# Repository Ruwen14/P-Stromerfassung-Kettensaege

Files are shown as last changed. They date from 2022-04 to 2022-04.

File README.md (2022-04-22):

# P-Stromerfassung-Kettensaege
Projektarbeit: Schaltungstechnik Master Mechatronik
- Aufgabenstellung:
  Messung des Dreiphasenstrom eines BLDC-Motors in einer Kettensäge

- Genutzte Technologien:
  -   LTSpice (Simulation)
  -   Eagle (Platinendesign & Layout)
  -   Reflow Ofen & Löteisen (Bestückung)

# Schematic
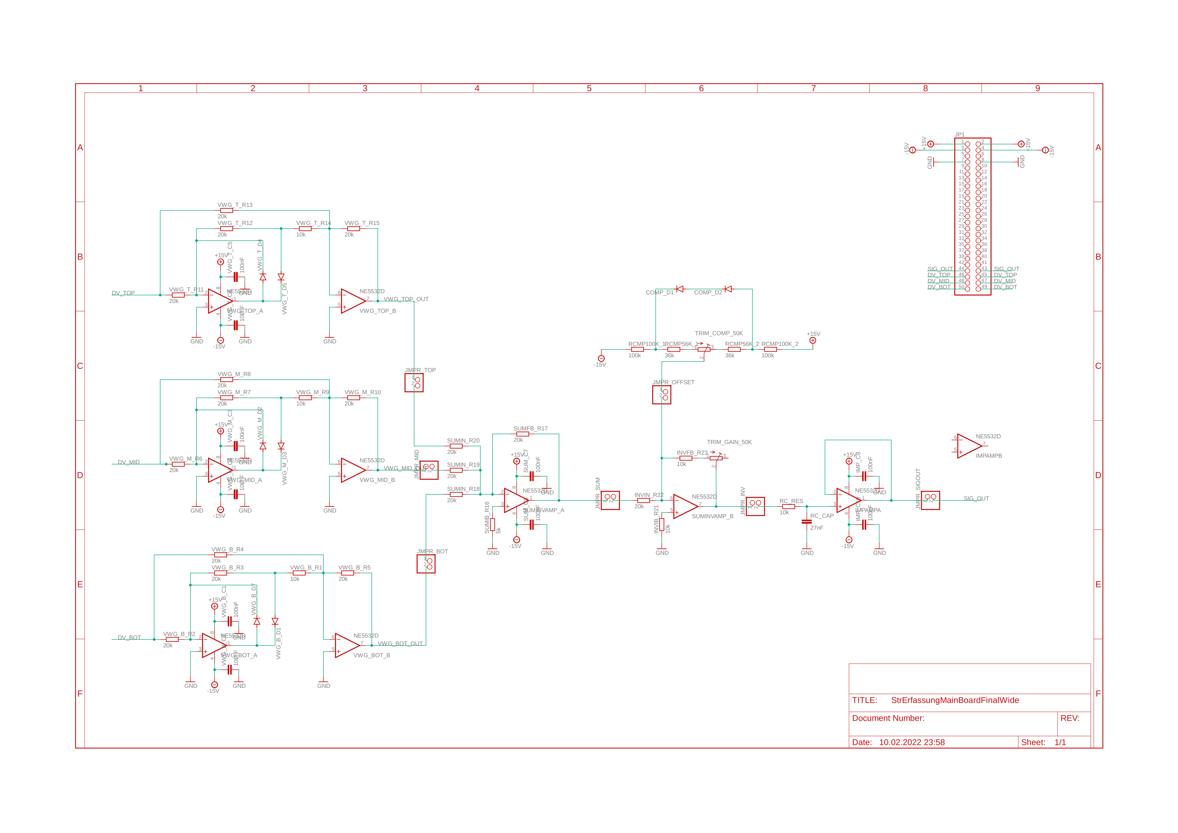
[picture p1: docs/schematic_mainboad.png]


# PCB
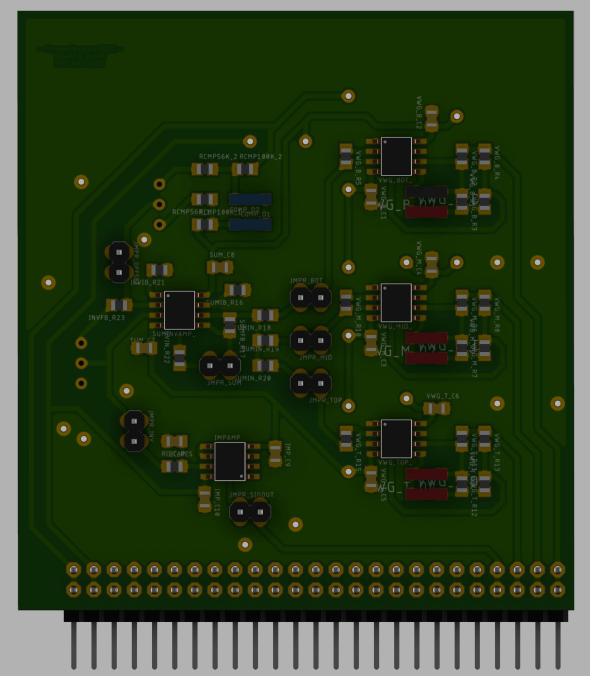
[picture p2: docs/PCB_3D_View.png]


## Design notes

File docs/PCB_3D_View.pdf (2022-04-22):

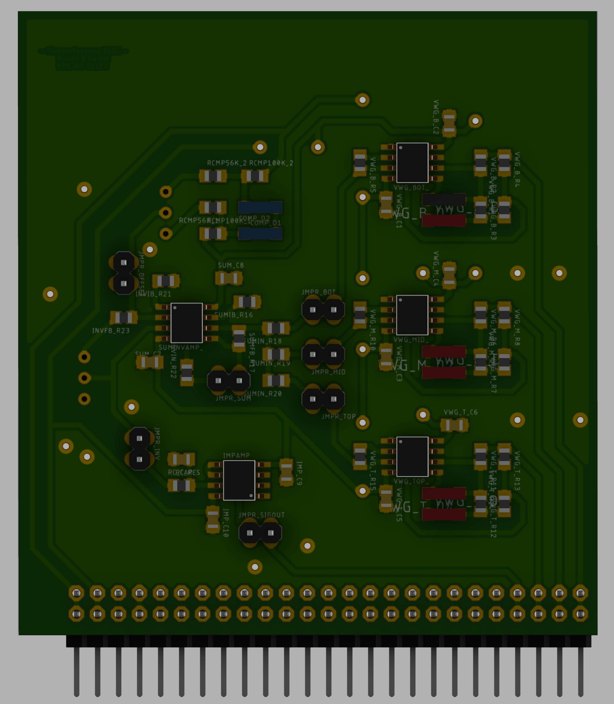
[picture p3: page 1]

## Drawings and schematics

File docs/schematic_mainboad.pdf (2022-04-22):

A

A

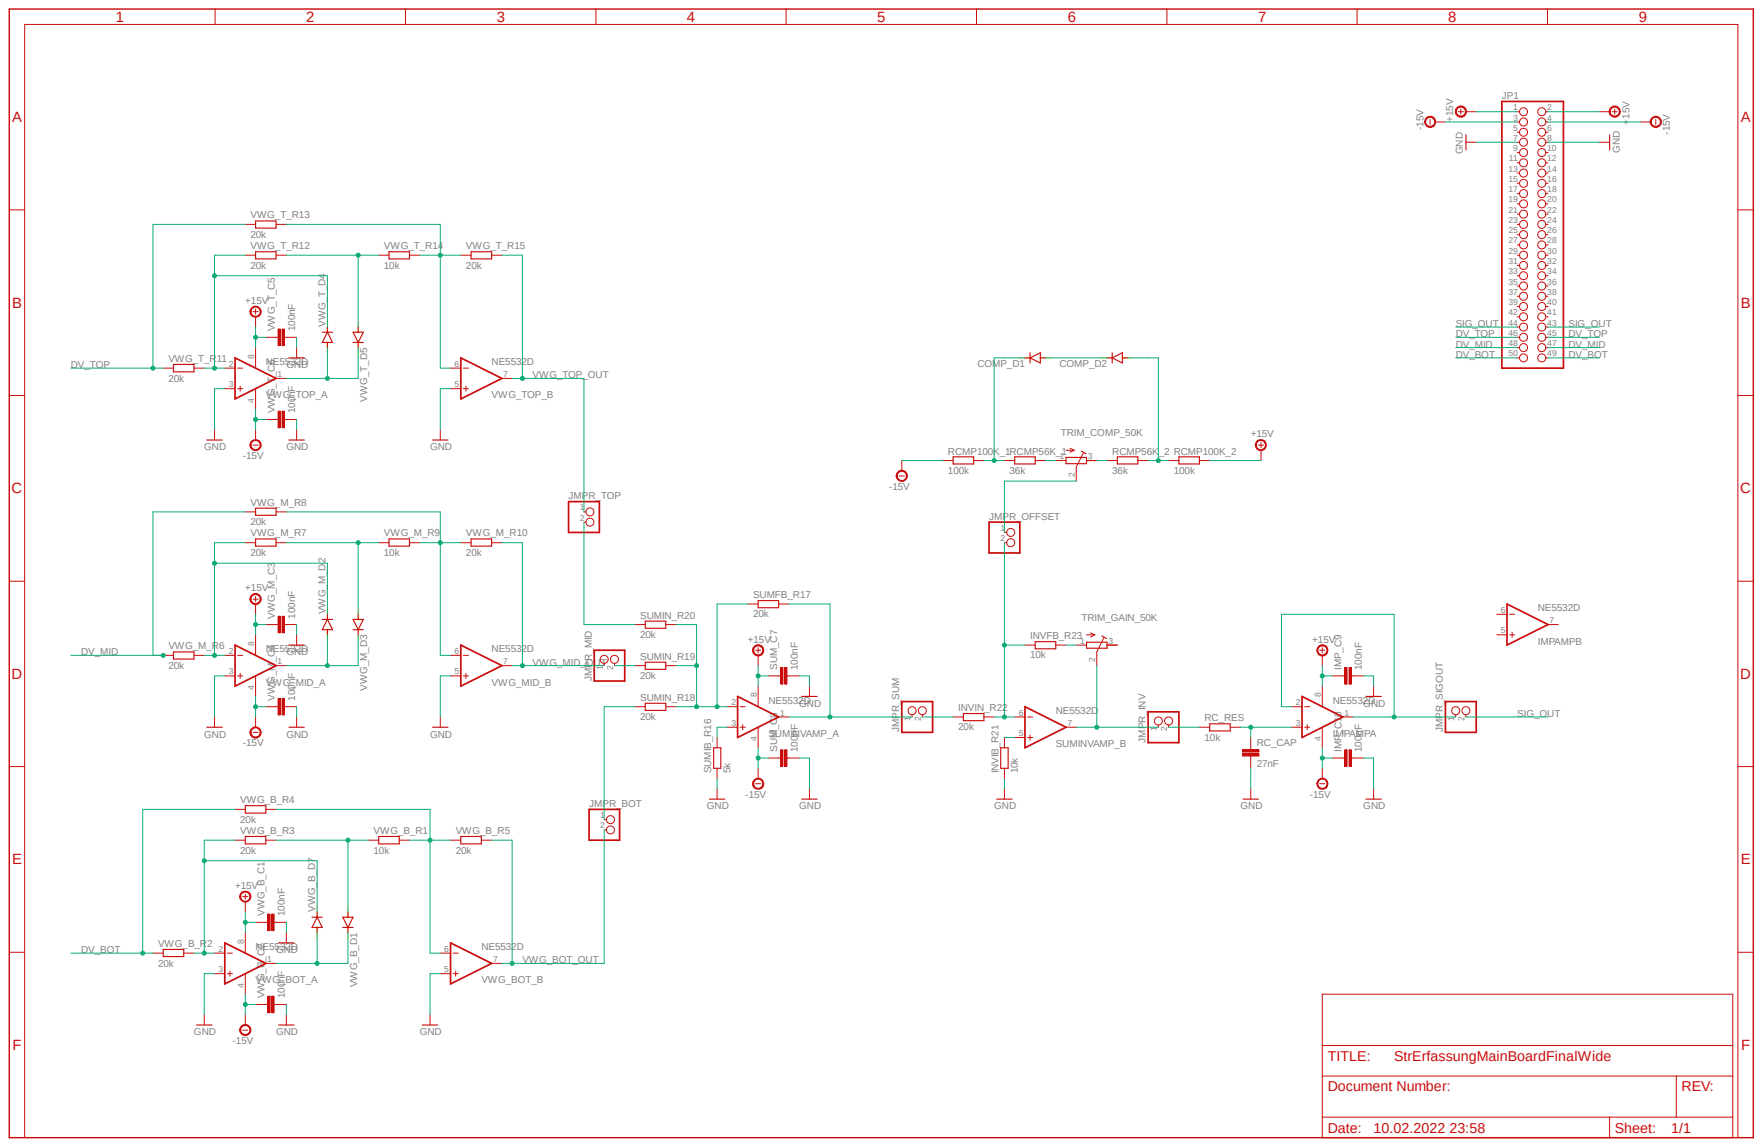
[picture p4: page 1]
SpiceOrder 2; SpiceOrder 1 SpiceOrder 1; GND; 100nF GND; 100nF GND ⁵k; VWG_BOT_A; VWG_BOT_B; VWG_B_R2; VWG_B_R3; VWG_B_R4; VWG_B_R1; VWG_B_R5 8 4; VWG_B_C¹ VWG_B_C²; VWG_MID_A; VWG_MID_B; VWG_M_R6; VWG_M_R7; VWG_M_R8; VWG_M_R9; VWG_M_R10 8 4; VWG_M_C³ VWG_M_C⁴; VWG_TOP_A; VWG_TOP_B; VWG_T_R11; VWG_T_R12; VWG_T_R13; VWG_T_R14; VWG_T_R15 8 4; VWG_T_C⁵ VWG_T_C⁶; SUMINVAMP_A; SUMINVAMP_B ⁸ ⁴; SUM_C⁷ SUM_C⁸ SUMIB_R¹⁶; SUMFB_R17; SUMIN_R18; SUMIN_R19; SUMIN_R20; INVIB_R²¹; INVIN_R22; INVFB_R23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

SpiceOrder 1 SpiceOrder 2 SpiceOrder 1 SpiceOrder 2 SpiceOrder 1 SpiceOrder 2

Document Number: | REV:

Date: 10.02.2022 23:58 | Sheet: 1/1

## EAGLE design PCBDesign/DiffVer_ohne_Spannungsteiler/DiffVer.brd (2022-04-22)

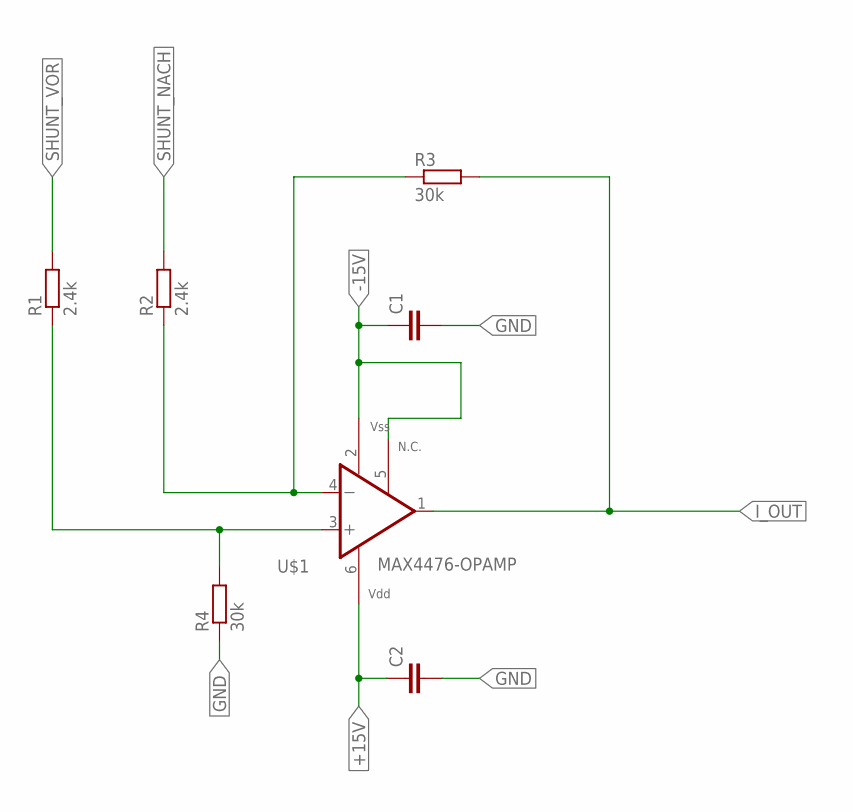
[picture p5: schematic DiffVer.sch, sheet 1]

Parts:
C1, C2: C-EUC0805; C0805
R1, R2: 2.4k; R0805
R3, R4: 30k; R0805
U$1: MAX4476-OPAMP; SOT23-6

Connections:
+15V: C2.1, U$1.6 (VDD); also elsewhere on the board
-15V: C1.1, U$1.2 (VSS), U$1.5 (NC); also elsewhere on the board
GND: C1.2, C2.2, R4.1; also elsewhere on the board
I_OUT: R3.2, U$1.1 (OUT); also elsewhere on the board
MINUS_OP: R2.1, R3.1, U$1.4 (-IN)
PLUS_OP: R1.1, R4.2, U$1.3 (+IN)
SHUNT_NACH: R2.2; also elsewhere on the board
SHUNT_VOR: R1.2; also elsewhere on the board

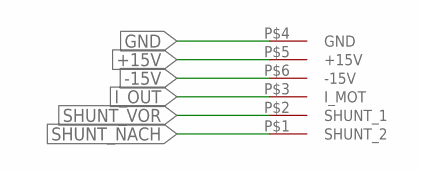
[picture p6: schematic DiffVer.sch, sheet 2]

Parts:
U$2: ADAPTERPLATINE_OPSHUNT

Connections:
+15V: U$2.P$5 (+15V); also elsewhere on the board
-15V: U$2.P$6 (-15V); also elsewhere on the board
GND: U$2.P$4 (GND); also elsewhere on the board
I_OUT: U$2.P$3 (I_MOT); also elsewhere on the board
SHUNT_NACH: U$2.P$1 (SHUNT_2); also elsewhere on the board
SHUNT_VOR: U$2.P$2 (SHUNT_1); also elsewhere on the board

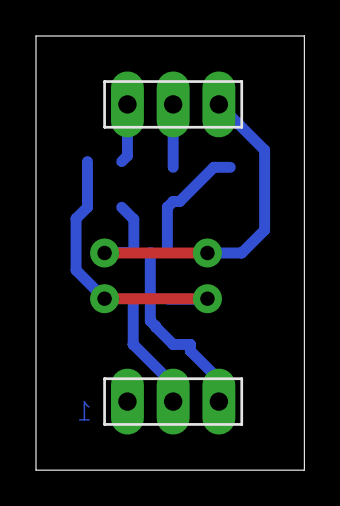
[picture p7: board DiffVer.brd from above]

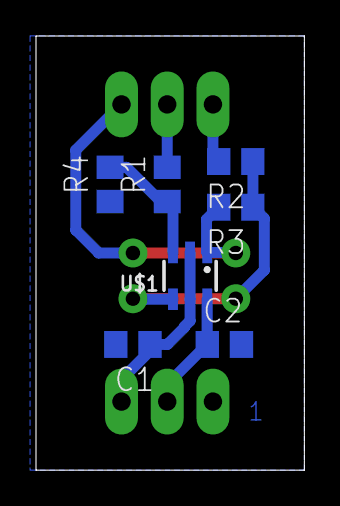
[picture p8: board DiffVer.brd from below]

Board: 2 copper layers, 14.9 x 24.1 mm, 8 parts (7 on the bottom side), 8 nets.

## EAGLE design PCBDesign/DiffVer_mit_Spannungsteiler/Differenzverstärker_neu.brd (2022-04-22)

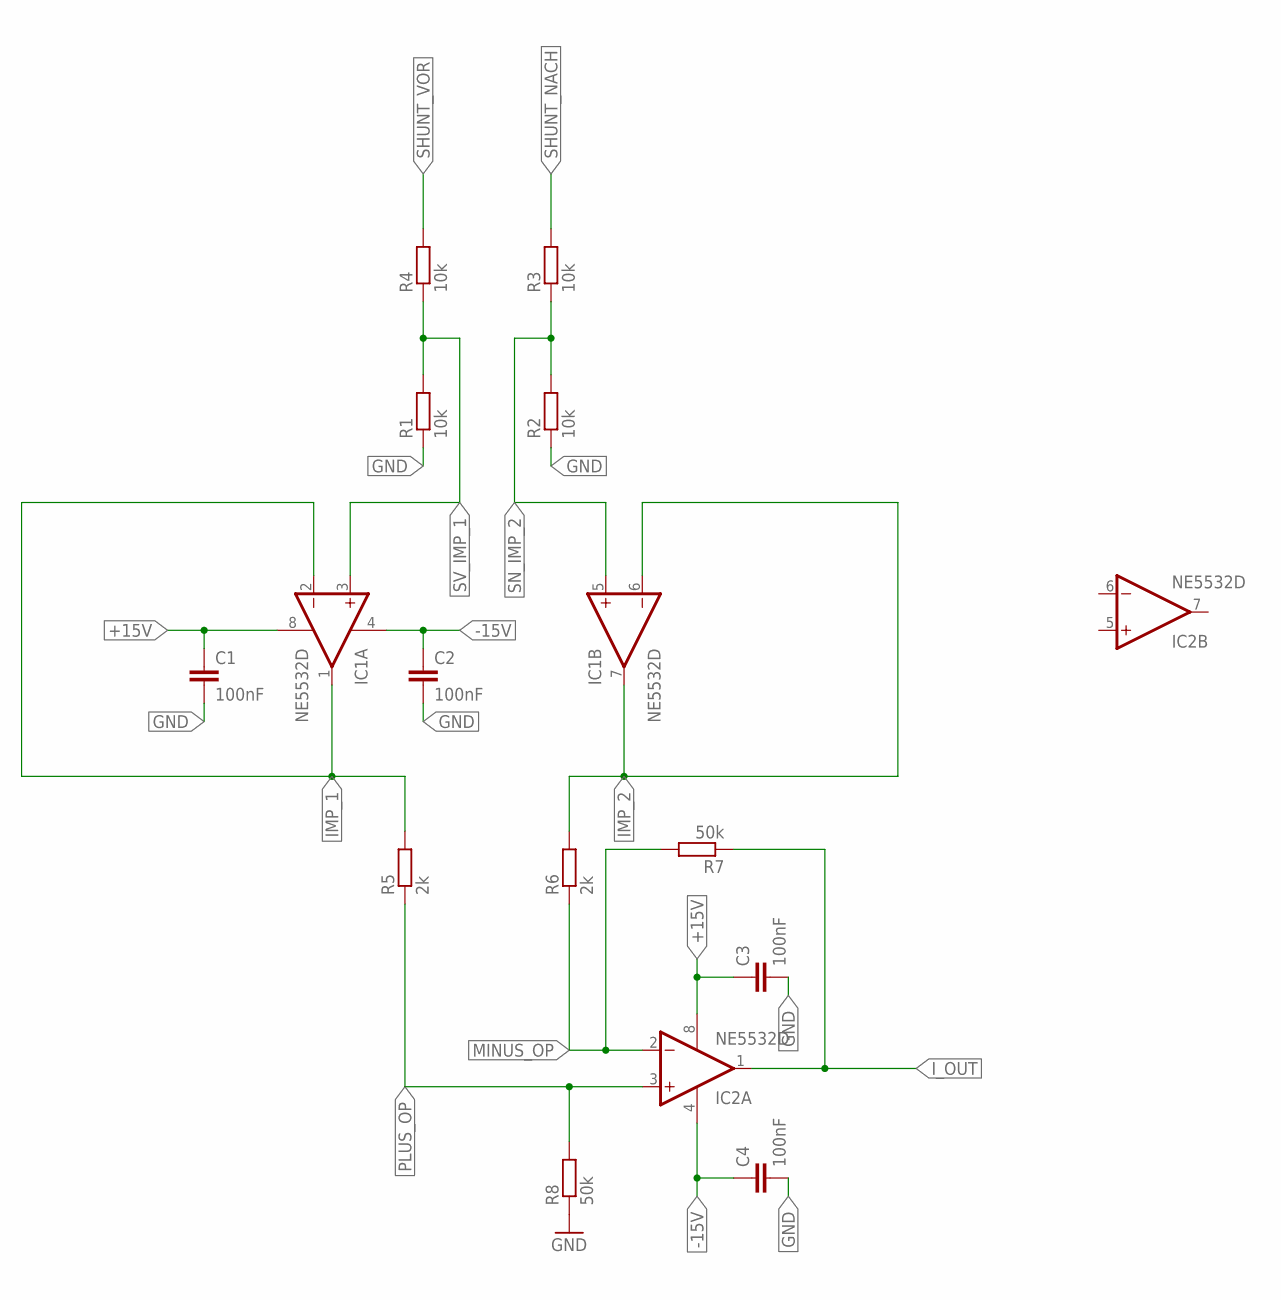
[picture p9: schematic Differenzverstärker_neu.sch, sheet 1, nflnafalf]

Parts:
C1, C2, C3, C4: 100nF; C0805
IC1, IC2: NE5532D; SO08
R1, R2, R3, R4: 10k; R0805
R5, R6: 2k; R0805
R7, R8: 50k; R0805

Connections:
+15V: C1.1, C3.1, IC1.8 (V+), IC2.8 (V+); also elsewhere on the board
-15V: C2.1, C4.1, IC1.4 (V-), IC2.4 (V-); also elsewhere on the board
GND: C1.2, C2.2, C3.2, C4.2, R1.1, R2.1, R8.1; also elsewhere on the board
IMP_1: IC1.1 (OUT), IC1.2 (-IN), R5.2
IMP_2: IC1.6 (-IN), IC1.7 (OUT), R6.2
I_OUT: IC2.1 (OUT), R7.1; also elsewhere on the board
MINUS_OP: IC2.2 (-IN), R6.1, R7.2
PLUS_OP: IC2.3 (+IN), R5.1, R8.2
SHUNT_NACH: R3.2; also elsewhere on the board
SHUNT_VOR: R4.2; also elsewhere on the board
SN_IMP_2: IC1.5 (+IN), R2.2, R3.1
SV_IMP_1: IC1.3 (+IN), R1.2, R4.1


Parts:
U$2: ADAPTERPLATINE_OPSHUNT

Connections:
+15V: U$2.P$5 (+15V); also elsewhere on the board
-15V: U$2.P$6 (-15V); also elsewhere on the board
GND: U$2.P$4 (GND); also elsewhere on the board
I_OUT: U$2.P$3 (I_MOT); also elsewhere on the board
SHUNT_NACH: U$2.P$1 (SHUNT_2); also elsewhere on the board
SHUNT_VOR: U$2.P$2 (SHUNT_1); also elsewhere on the board

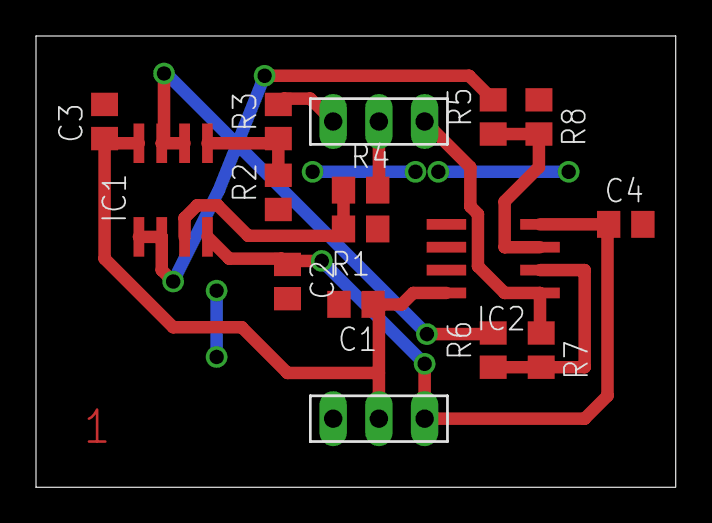
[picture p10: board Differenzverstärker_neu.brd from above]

Board: 2 copper layers, 35.5 x 25.1 mm, 15 parts (0 on the bottom side), 12 nets.

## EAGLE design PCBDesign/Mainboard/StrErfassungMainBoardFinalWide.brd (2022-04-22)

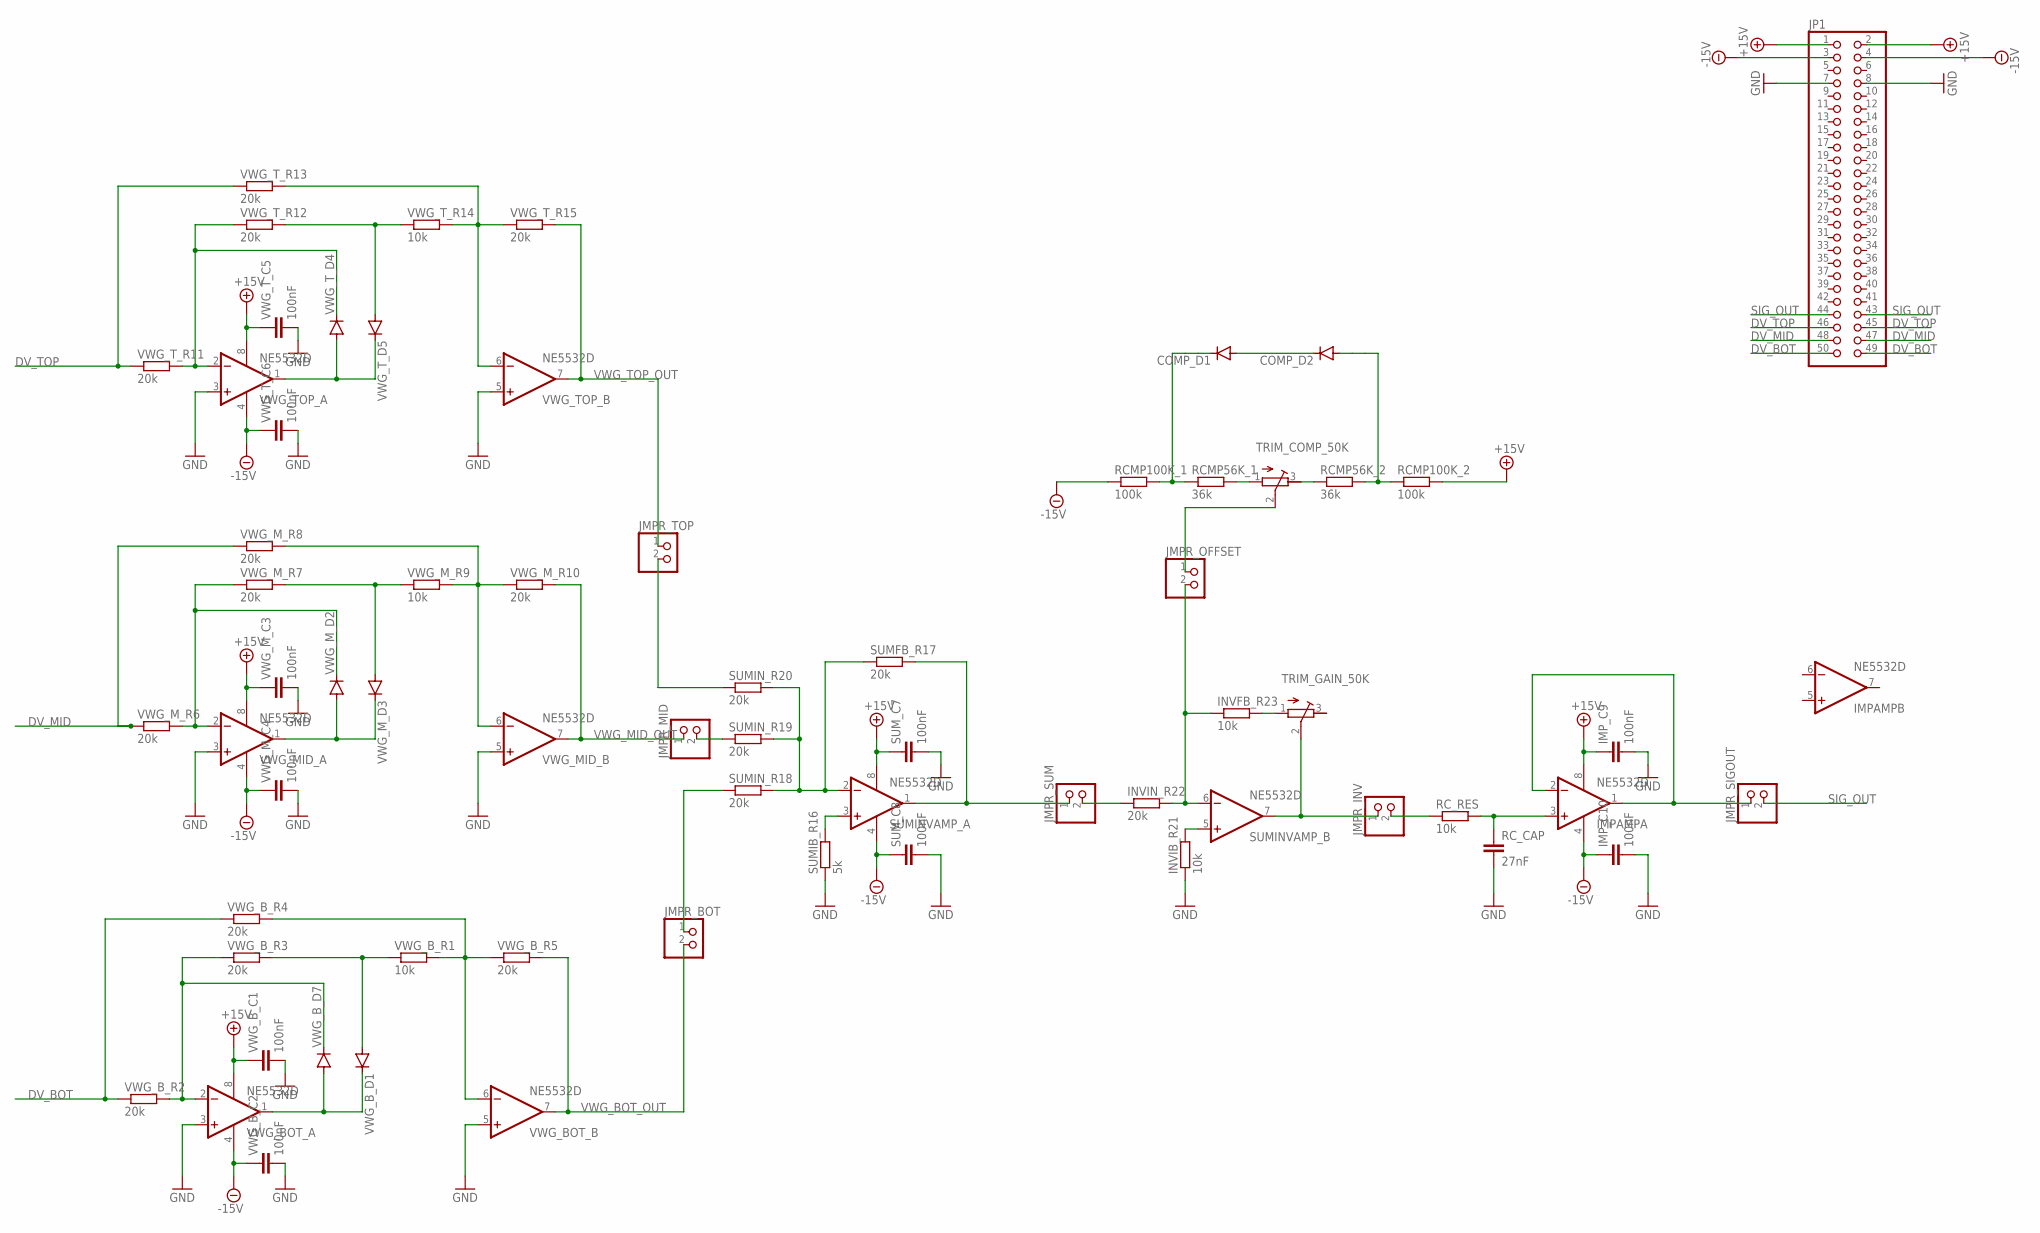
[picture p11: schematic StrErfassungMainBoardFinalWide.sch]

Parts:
COMP_D1, COMP_D2: DIODE-SOD123; SOD123
IMPAMP: NE5532D; SO08
IMP_C9, IMP_C10: 100nF; C0805
INVFB_R23: 10k; R0805
INVIB_R21: 10k; R0805
INVIN_R22: 20k; R0805
JMPR_BOT: PINHD-1X2; 1X02
JMPR_INV: PINHD-1X2; 1X02
JMPR_MID: PINHD-1X2; 1X02
JMPR_OFFSET: PINHD-1X2; 1X02
JMPR_SIGOUT: PINHD-1X2; 1X02
JMPR_SUM: PINHD-1X2; 1X02
JMPR_TOP: PINHD-1X2; 1X02
JP1: PINHD-2X25/90; 2X25/90
RCMP56K_1, RCMP56K_2: 36k; R0805
RCMP100K_1, RCMP100K_2: 100k; R0805
RC_CAP: 27nF; C0805
RC_RES: 10k; R0805
SUMFB_R17: 20k; R0805
SUMIB_R16: 5k; R0805
SUMINVAMP_: NE5532D; SO08
SUMIN_R18, SUMIN_R19, SUMIN_R20: 20k; R0805
SUM_C7, SUM_C8: 100nF; C0805
TRIM_COMP_50K: R-TRIMM3296W; RTRIM3296W
TRIM_GAIN_50K: R-TRIMM3296W; RTRIM3296W
VWG_BOT_: NE5532D; SO08
VWG_B_C1, VWG_B_C2: 100nF; C0805
VWG_B_D1, VWG_B_D7: DIODE-SOD123; SOD123
VWG_B_R1: 10k; R0805
VWG_B_R2, VWG_B_R3, VWG_B_R4, VWG_B_R5: 20k; R0805
VWG_MID_: NE5532D; SO08
VWG_M_C3, VWG_M_C4: 100nF; C0805
VWG_M_D2, VWG_M_D3: DIODE-SOD123; SOD123
VWG_M_R6, VWG_M_R7, VWG_M_R8, VWG_M_R10: 20k; R0805
VWG_M_R9: 10k; R0805
VWG_TOP_: NE5532D; SO08
VWG_T_C5, VWG_T_C6: 100nF; C0805
VWG_T_D4, VWG_T_D5: DIODE-SOD123; SOD123
VWG_T_R11, VWG_T_R12, VWG_T_R13, VWG_T_R15: 20k; R0805
VWG_T_R14: 10k; R0805

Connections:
+15V: IMPAMP.8 (V+), IMP_C9.1, JP1.1, JP1.2, RCMP100K_2.2, SUMINVAMP_.8 (V+), SUM_C7.1, VWG_BOT_.8 (V+), VWG_B_C1.1, VWG_MID_.8 (V+), VWG_M_C3.1, VWG_TOP_.8 (V+), VWG_T_C5.1
-15V: IMPAMP.4 (V-), IMP_C10.1, JP1.3, JP1.4, RCMP100K_1.1, SUMINVAMP_.4 (V-), SUM_C8.1, VWG_BOT_.4 (V-), VWG_B_C2.1, VWG_MID_.4 (V-), VWG_M_C4.1, VWG_TOP_.4 (V-), VWG_T_C6.1
DV_BOT: JP1.49 (50), JP1.50 (49), VWG_B_R2.1, VWG_B_R4.1
DV_MID: JP1.47 (48), JP1.48 (47), VWG_M_R6.1, VWG_M_R8.1
DV_TOP: JP1.45 (46), JP1.46 (45), VWG_T_R11.1, VWG_T_R13.1
GND: IMP_C9.2, IMP_C10.2, INVIB_R21.1, JP1.7, JP1.8, RC_CAP.2, SUMIB_R16.1, SUM_C7.2, SUM_C8.2, VWG_BOT_.3 (+IN), VWG_BOT_.5 (+IN), VWG_B_C1.2, VWG_B_C2.2, VWG_MID_.3 (+IN), VWG_MID_.5 (+IN), VWG_M_C3.2, VWG_M_C4.2, VWG_TOP_.3 (+IN), VWG_TOP_.5 (+IN), VWG_T_C5.2, VWG_T_C6.2
JMPR_INV: JMPR_INV.1, SUMINVAMP_.7 (OUT), TRIM_GAIN_50K.2 (S)
unnamed: VWG_B_D1.A, VWG_B_R1.1, VWG_B_R3.2
unnamed: VWG_BOT_.1 (OUT), VWG_B_D1.C, VWG_B_D7.A
unnamed: VWG_MID_.2 (-IN), VWG_M_D2.C, VWG_M_R6.2, VWG_M_R7.1
unnamed: VWG_M_D3.A, VWG_M_R7.2, VWG_M_R9.1
unnamed: VWG_BOT_.6 (-IN), VWG_B_R1.2, VWG_B_R4.2, VWG_B_R5.1
unnamed: VWG_MID_.1 (OUT), VWG_M_D2.A, VWG_M_D3.C
unnamed: SUMFB_R17.1, SUMINVAMP_.2 (-IN), SUMIN_R18.2, SUMIN_R19.2, SUMIN_R20.2
unnamed: VWG_MID_.6 (-IN), VWG_M_R8.2, VWG_M_R9.2, VWG_M_R10.1
unnamed: INVIB_R21.2, SUMINVAMP_.5 (+IN)
unnamed: VWG_TOP_.2 (-IN), VWG_T_D4.C, VWG_T_R11.2, VWG_T_R12.1
unnamed: VWG_T_D5.A, VWG_T_R12.2, VWG_T_R14.1
unnamed: VWG_TOP_.1 (OUT), VWG_T_D4.A, VWG_T_D5.C
unnamed: VWG_TOP_.6 (-IN), VWG_T_R13.2, VWG_T_R14.2, VWG_T_R15.1
unnamed: INVFB_R23.1, INVIN_R22.2, JMPR_OFFSET.2, SUMINVAMP_.6 (-IN)
unnamed: SUMIB_R16.2, SUMINVAMP_.3 (+IN)
unnamed: JMPR_OFFSET.1, TRIM_COMP_50K.2 (S)
unnamed: JMPR_SUM.1, SUMFB_R17.2, SUMINVAMP_.1 (OUT)
unnamed: IMPAMP.3 (+IN), RC_CAP.1, RC_RES.2
unnamed: RCMP56K_2.1, TRIM_COMP_50K.3 (E)
unnamed: COMP_D2.A, RCMP56K_2.2, RCMP100K_2.1
unnamed: COMP_D1.C, RCMP56K_1.1, RCMP100K_1.2
unnamed: RCMP56K_1.2, TRIM_COMP_50K.1 (A)
unnamed: COMP_D1.A, COMP_D2.C
unnamed: INVFB_R23.2, TRIM_GAIN_50K.1 (A)
unnamed: INVIN_R22.1, JMPR_SUM.2
unnamed: JMPR_BOT.1, SUMIN_R18.1
unnamed: JMPR_TOP.2, SUMIN_R20.1
unnamed: JMPR_MID.2, SUMIN_R19.1
unnamed: JMPR_INV.2, RC_RES.1
SIG_OUT: IMPAMP.1 (OUT), IMPAMP.2 (-IN), JMPR_SIGOUT.1, JMPR_SIGOUT.2, JP1.43 (44), JP1.44 (43)
VWG_BOT_OUT: JMPR_BOT.2, VWG_BOT_.7 (OUT), VWG_B_R5.2
VWG_IN-: VWG_BOT_.2 (-IN), VWG_B_D7.C, VWG_B_R2.2, VWG_B_R3.1
VWG_MID_OUT: JMPR_MID.1, VWG_MID_.7 (OUT), VWG_M_R10.2
VWG_TOP_OUT: JMPR_TOP.1, VWG_TOP_.7 (OUT), VWG_T_R15.2

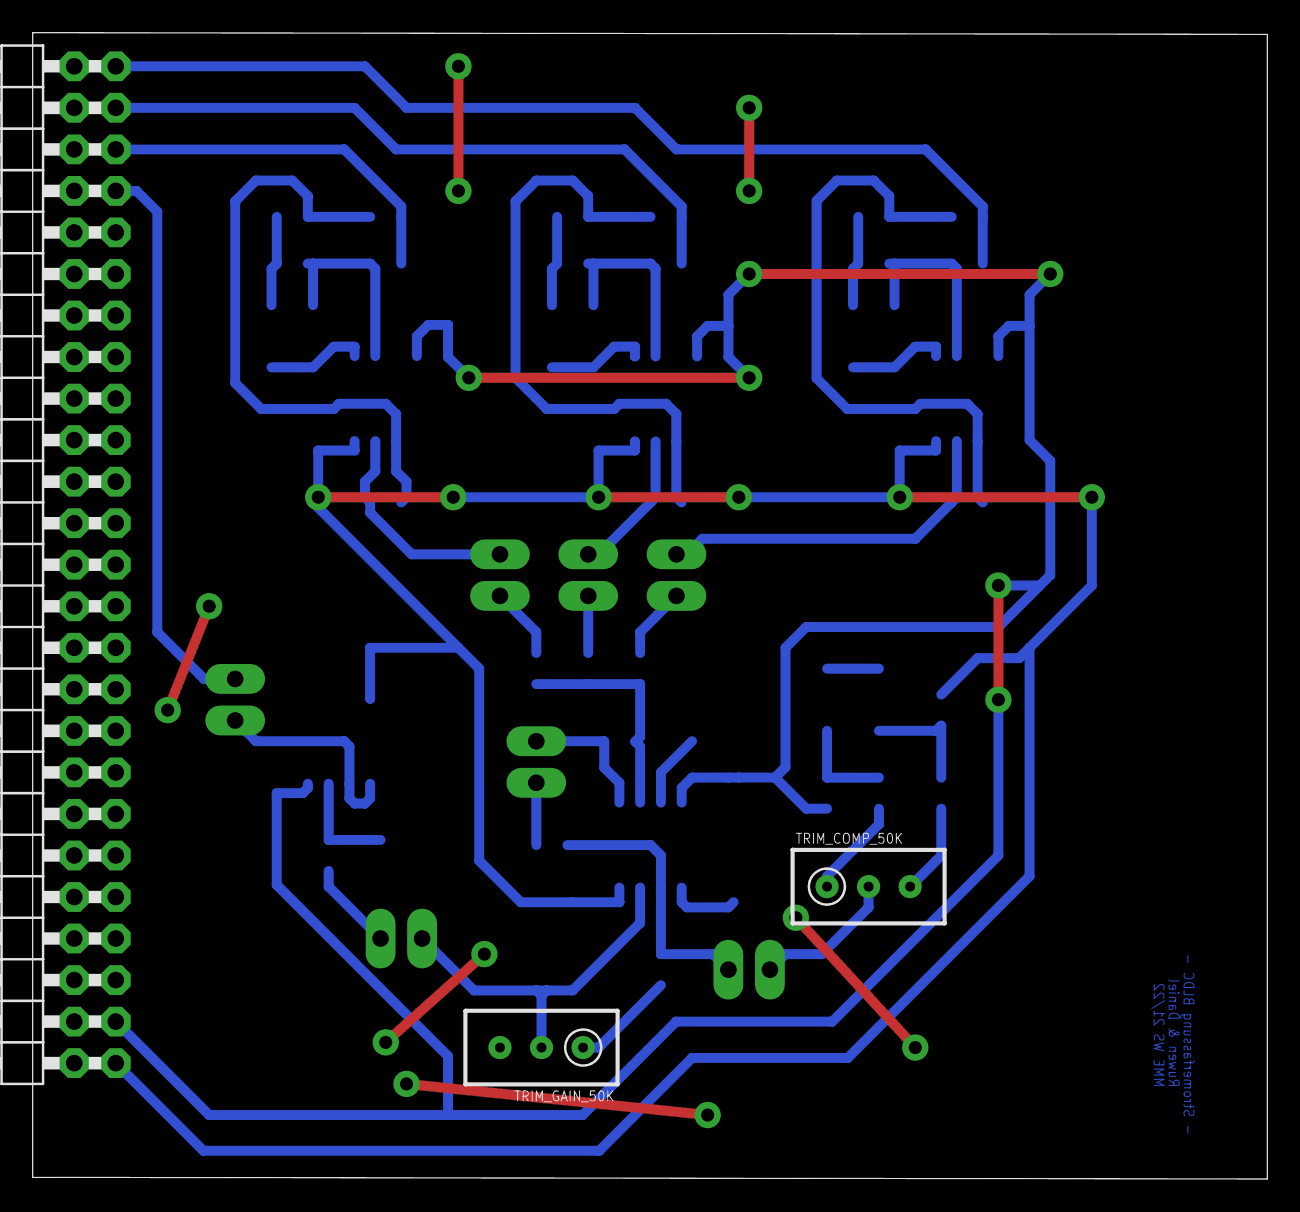
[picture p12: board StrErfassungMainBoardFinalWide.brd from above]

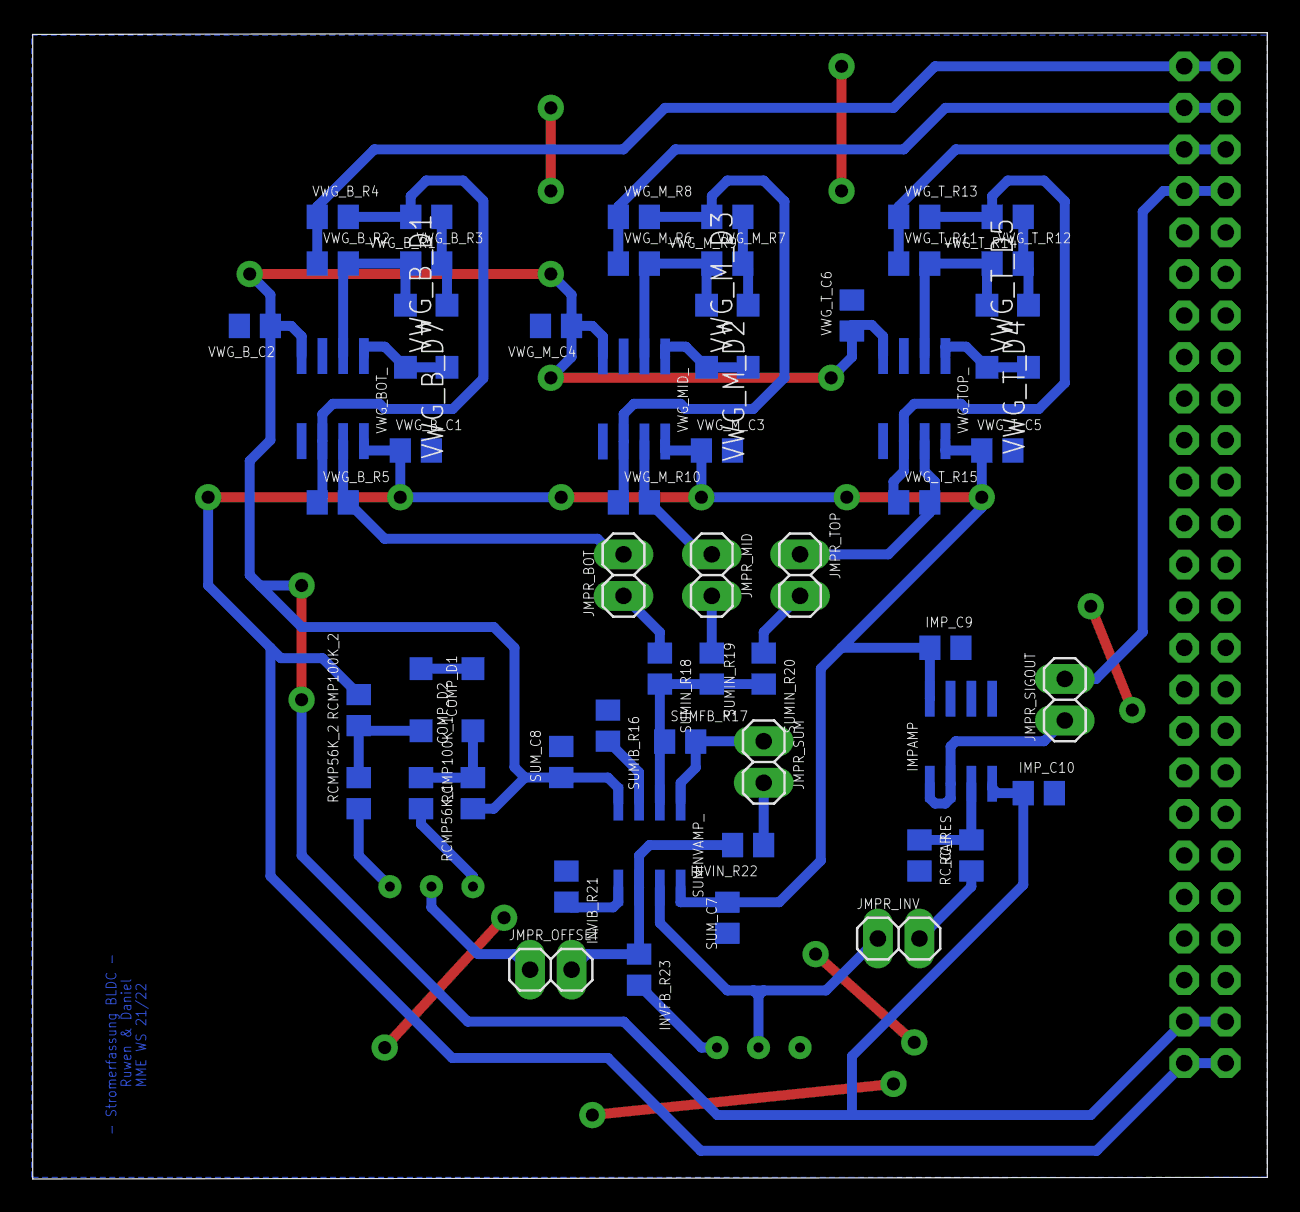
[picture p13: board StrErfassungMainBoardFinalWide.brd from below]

Board: 2 copper layers, 75.5 x 70.1 mm, 62 parts (59 on the bottom side), 41 nets.

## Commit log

2022-04-22 Add PCB-Design Files
    [DiffVer.brd, DiffVer.sch, Differenzverstärker_neu.brd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]
2022-04-22 added schematic
2022-04-22 added pcb view
